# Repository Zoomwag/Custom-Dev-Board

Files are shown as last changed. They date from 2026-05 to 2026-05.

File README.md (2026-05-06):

# RP2040 Development Board

---

## Overview

This dev board is based on the Raspberry Pi RP2040 microcontroller that i deigned to learn how MCUS work
---

##  Features

- RP2040 dual-core ARM Cortex-M0+ microcontroller
- USB C interface for power and programming (much better than the picos micro usb)
- GPIO breakout for easy access
- On-board voltage regulation
- Compact and clean PCB layout

---

##  Images

### Schematic

Here you can see the schematic. I tried my best to adhere to good schemtic pratcies and i actually think that i did pretty good.

### PCB Layout

Here we can see the fully routed PCB

### 3D Model


Here you can see a 3d model of the PCB

---

---

##  Getting Started

1. Flash firmware using USB
2. Connect peripherals via GPIO
3. Start building your project

The board can then be programmed in micro python

---

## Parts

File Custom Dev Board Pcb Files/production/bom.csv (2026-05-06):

Designator | Footprint | Quantity | Value | LCSC Part #
C1, C10, C11, C17, C2, C3, C4, C5, C6, C7, C8 | 0402 | 11 | 0.1 uF
C12, C9 | 0402 | 2 | 1 uF
C13, C14 | 0603 | 2 | 10uF
C15, C16 | 0402 | 2 | 33pF
J1 | USB_C_Receptacle_HRO_TYPE-C-31-M-12 | 1 | USB_C_Receptacle_USB2.0_14P
J2, J3 | PinHeader_1x20_P2.54mm_Vertical | 2 | Conn_01x20
J4 | PinHeader_1x03_P2.54mm_Vertical | 1 | Conn_01x03
R1, R2 | 0402 | 2 | 5.1K
R3, R4 | 0402 | 2 | 27
R5 | 0402 | 1 | 5K
R6 | 0402 | 1 | 1K
R7 | 0402 | 1 | 10K
SW1 | SW_Push_SPST_NO_Alps_SKRK | 1 | SW_Push
U1 | QFN-56-1EP_7x7mm_P0.4mm_EP3.2x3.2mm | 1 | RP2040
U3 | Winbond_USON-8-1EP_3x2mm_P0.5mm_EP0.2x1.6mm | 1 | W25Q16JVZPIQ TR
U4 | SOT-23 | 1 | MCP1700x-330xxTT
Y2 | Crystal_SMD_3225-4Pin_3.2x2.5mm | 1 | Crystal_GND24

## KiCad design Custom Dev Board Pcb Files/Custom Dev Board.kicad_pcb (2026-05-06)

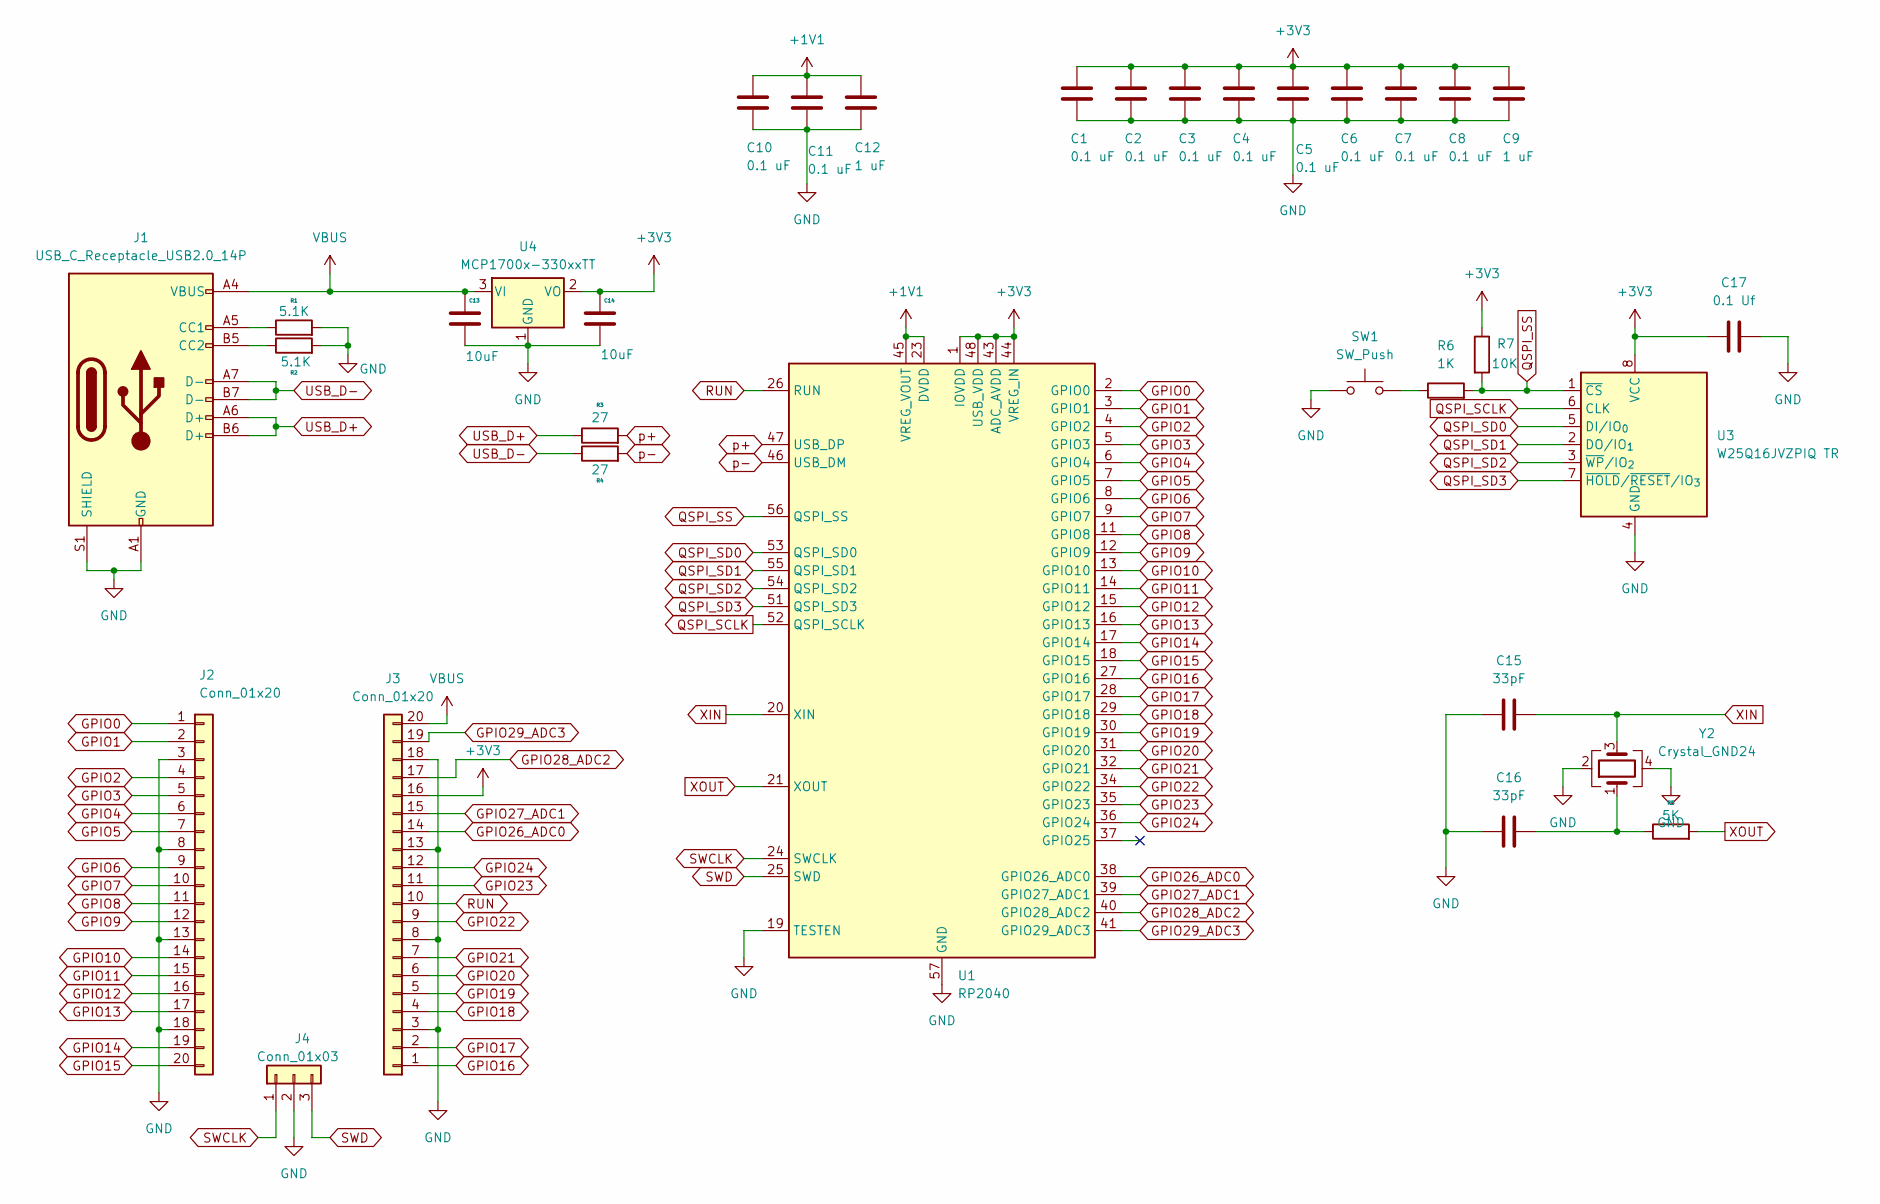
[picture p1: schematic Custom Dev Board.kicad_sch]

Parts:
C1, C2, C3, C4, C5, C6, C7, C8, C10, C11: 0.1 uF; C_0402_1005Metric
C9, C12: 1 uF; C_0402_1005Metric
C13, C14: 10uF; C_0603_1608Metric
C15, C16: 33pF; C_0402_1005Metric
C17: 0.1 Uf; C_0402_1005Metric
J1: USB_C_Receptacle_USB2.0_14P; USB_C_Receptacle_HRO_TYPE-C-31-M-12
J2, J3: Conn_01x20; PinHeader_1x20_P2.54mm_Vertical
J4: Conn_01x03; PinHeader_1x03_P2.54mm_Vertical
R1, R2: 5.1K; R_0402_1005Metric
R3, R4: 27; R_0402_1005Metric
R5: 5K; R_0402_1005Metric
R6: 1K; R_0402_1005Metric
R7: 10K; R_0402_1005Metric
SW1: SW_Push; SW_Push_SPST_NO_Alps_SKRK
U1: RP2040; QFN-56-1EP_7x7mm_P0.4mm_EP3.2x3.2mm
U3: W25Q16JVZPIQ TR; Winbond_USON-8-1EP_3x2mm_P0.5mm_EP0.2x1.6mm
U4: MCP1700x-330xxTT; SOT-23
Y2: Crystal_GND24; Crystal_SMD_3225-4Pin_3.2x2.5mm

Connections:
+1V1: C10.1, C11.1, C12.1, U1.23 (DVDD), U1.45 (VREG_VOUT), U1.50 (DVDD)
+3V3: C1.1, C2.1, C3.1, C4.1, C5.1, C6.1, C7.1, C8.1, C9.1, C14.1, C17.1, J3.16, R7.1, U1.1 (IOVDD), U1.10 (IOVDD), U1.22 (IOVDD), U1.33 (IOVDD), U1.42 (IOVDD), U1.43 (ADC_AVDD), U1.44 (VREG_IN), U1.48 (USB_VDD), U1.49 (IOVDD), U3.8 (VCC), U4.2 (VO)
GND: C1.2, C2.2, C3.2, C4.2, C5.2, C6.2, C7.2, C8.2, C9.2, C10.2, C11.2, C12.2, C13.2, C14.2, C15.1, C16.1, C17.2, J1.A1 (GND), J1.A12 (GND), J1.B1 (GND), J1.B12 (GND), J1.S1 (SHIELD), J2.3, J2.8, J2.13, J2.18, J3.3, J3.8, J3.13, J3.18, J4.2, R1.2, R2.2, SW1.1, U1.19 (TESTEN), U1.57 (GND), U3.4 (GND), U4.1 (GND), Y2.2, Y2.4
GPIO0: J2.1, U1.2 (GPIO0)
GPIO1: J2.2, U1.3 (GPIO1)
GPIO2: J2.4, U1.4 (GPIO2)
GPIO3: J2.5, U1.5 (GPIO3)
GPIO4: J2.6, U1.6 (GPIO4)
GPIO5: J2.7, U1.7 (GPIO5)
GPIO6: J2.9, U1.8 (GPIO6)
GPIO7: J2.10, U1.9 (GPIO7)
GPIO8: J2.11, U1.11 (GPIO8)
GPIO9: J2.12, U1.12 (GPIO9)
GPIO10: J2.14, U1.13 (GPIO10)
GPIO11: J2.15, U1.14 (GPIO11)
GPIO12: J2.16, U1.15 (GPIO12)
GPIO13: J2.17, U1.16 (GPIO13)
GPIO14: J2.19, U1.17 (GPIO14)
GPIO15: J2.20, U1.18 (GPIO15)
GPIO16: J3.1, U1.27 (GPIO16)
GPIO17: J3.2, U1.28 (GPIO17)
GPIO18: J3.4, U1.29 (GPIO18)
GPIO19: J3.5, U1.30 (GPIO19)
GPIO20: J3.6, U1.31 (GPIO20)
GPIO21: J3.7, U1.32 (GPIO21)
GPIO22: J3.9, U1.34 (GPIO22)
GPIO23: J3.11, U1.35 (GPIO23)
GPIO24: J3.12, U1.36 (GPIO24)
GPIO26_ADC0: J3.14, U1.38 (GPIO26_ADC0)
GPIO27_ADC1: J3.15, U1.39 (GPIO27_ADC1)
GPIO28_ADC2: J3.17, U1.40 (GPIO28_ADC2)
GPIO29_ADC3: J3.19, U1.41 (GPIO29_ADC3)
unnamed: C16.2, R5.1, Y2.1
unnamed: J1.A5 (CC1), R1.1
unnamed: J1.B5 (CC2), R2.1
unnamed: R6.1, SW1.2
QSPI_SCLK: U1.52 (QSPI_SCLK), U3.6 (CLK)
QSPI_SD0: U1.53 (QSPI_SD0), U3.5 (DI/IO_{0})
QSPI_SD1: U1.55 (QSPI_SD1), U3.2 (DO/IO_{1})
QSPI_SD2: U1.54 (QSPI_SD2), U3.3 (~WP/IO_{2})
QSPI_SD3: U1.51 (QSPI_SD3), U3.7 (~HOLD/~RESET/IO_{3})
QSPI_SS: R6.2, R7.2, U1.56 (QSPI_SS), U3.1 (~CS)
RUN: J3.10, U1.26 (RUN)
SWCLK: J4.1, U1.24 (SWCLK)
SWD: J4.3, U1.25 (SWD)
USB_D+: J1.A6 (D+), J1.B6 (D+), R3.1
USB_D-: J1.A7 (D-), J1.B7 (D-), R4.1
VBUS: C13.1, J1.A4 (VBUS), J1.A9 (VBUS), J1.B4 (VBUS), J1.B9 (VBUS), J3.20, U4.3 (VI)
XIN: C15.2, U1.20 (XIN), Y2.3
XOUT: R5.2, U1.21 (XOUT)
p+: R3.2, U1.47 (USB_DP)
p-: R4.2, U1.46 (USB_DM)

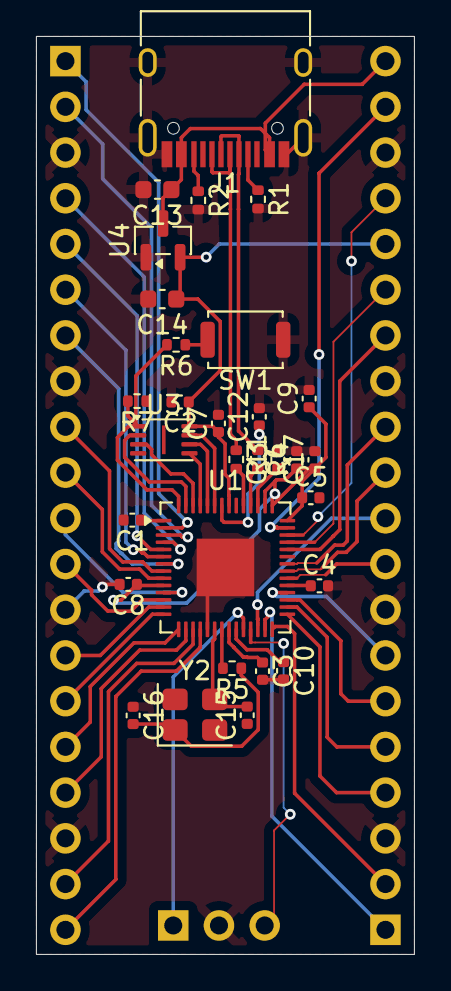
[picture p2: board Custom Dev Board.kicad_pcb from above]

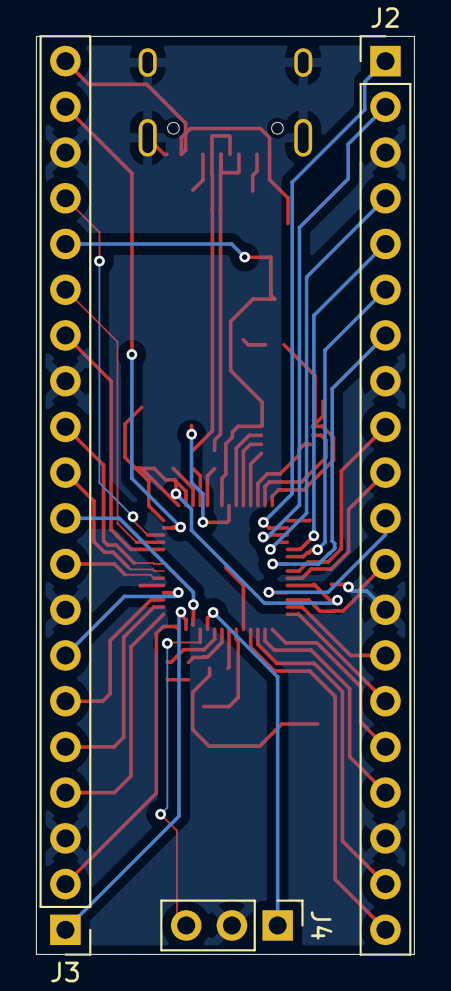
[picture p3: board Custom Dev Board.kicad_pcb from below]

Board: 2 copper layers, 21.0 x 51.0 mm, 33 parts (3 on the bottom side), 52 nets.
